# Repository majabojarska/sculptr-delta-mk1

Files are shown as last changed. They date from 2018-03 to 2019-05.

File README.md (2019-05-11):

# Sculptr Delta MK1

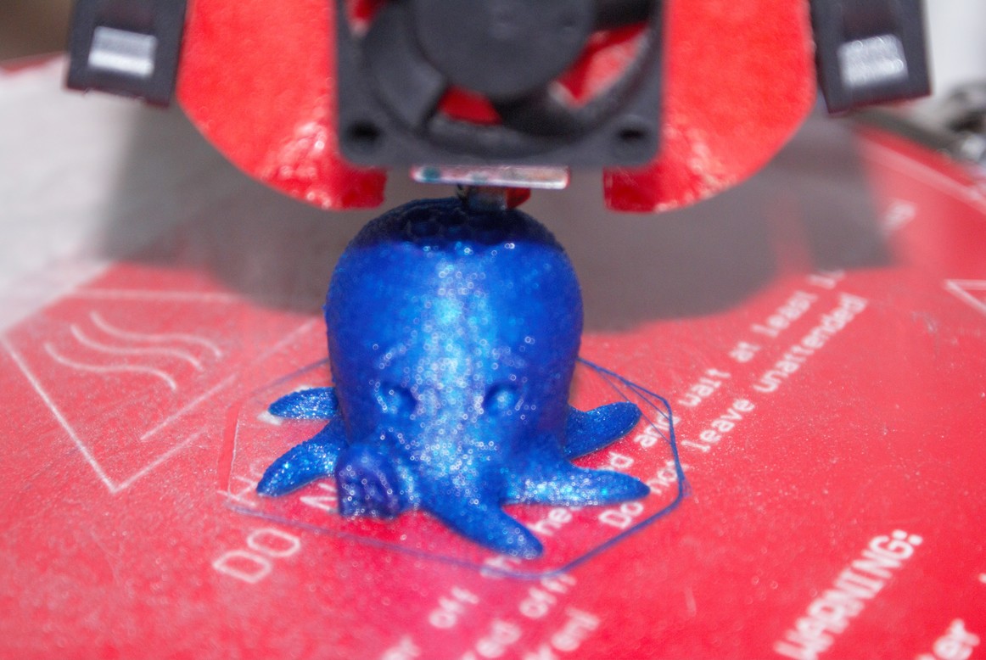
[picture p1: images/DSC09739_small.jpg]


## About

This is a modified version of the generic Marlin-1.1.x firmware pulled from the original github repository.
It's been set up to work with my build of Sculptr Delta MK1.
Might need a bit of tweaking to fully work with yours :) .

## Hardware description
- RAMPS 1.4 EFB
- RepRapDiscount FULL GRAPHIC Smart Controller
- 4xA4988 Stepper Drivers
- Normally closed (NC) endstops
- ATX PSU wired to power the hotend and heatbed from two separate channels
- E3Dv6 12V hotend
- MK2Y 220mm 12V circular heatbed with 4mm glass on top
- 100kOhm thermocouples
- Replaced heatbed MOSFET to IRLB3034 - more efficient, can handle higher loads easily with a small heatsink, generates much less heat
- OctoPrint hosted on Raspberry Pi 3 with a video stream
- 2x NeoPixel LEDs for print lighting

## Images
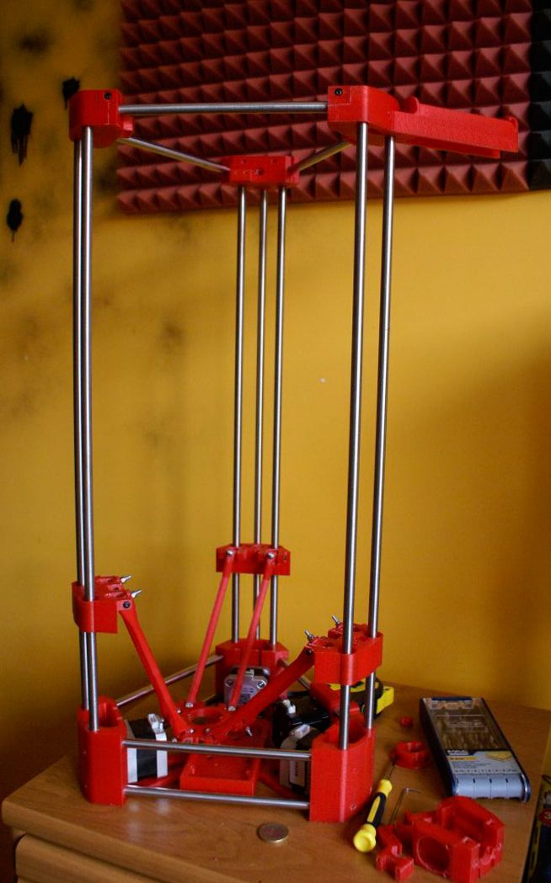
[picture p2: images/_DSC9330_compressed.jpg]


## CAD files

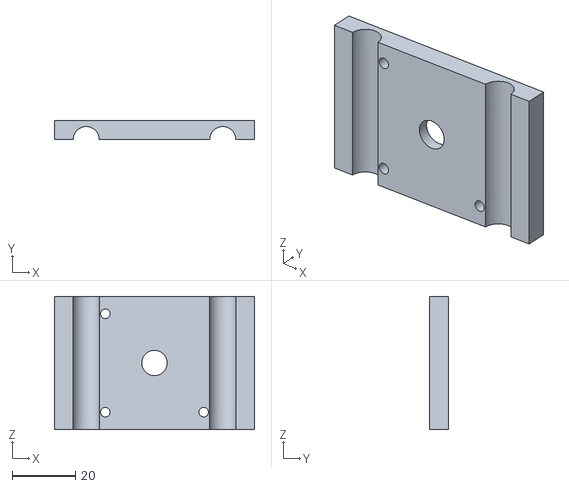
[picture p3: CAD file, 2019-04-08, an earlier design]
Thingiverse/files/extruder_support2.stl
63.0 x 6.00 x 42.0

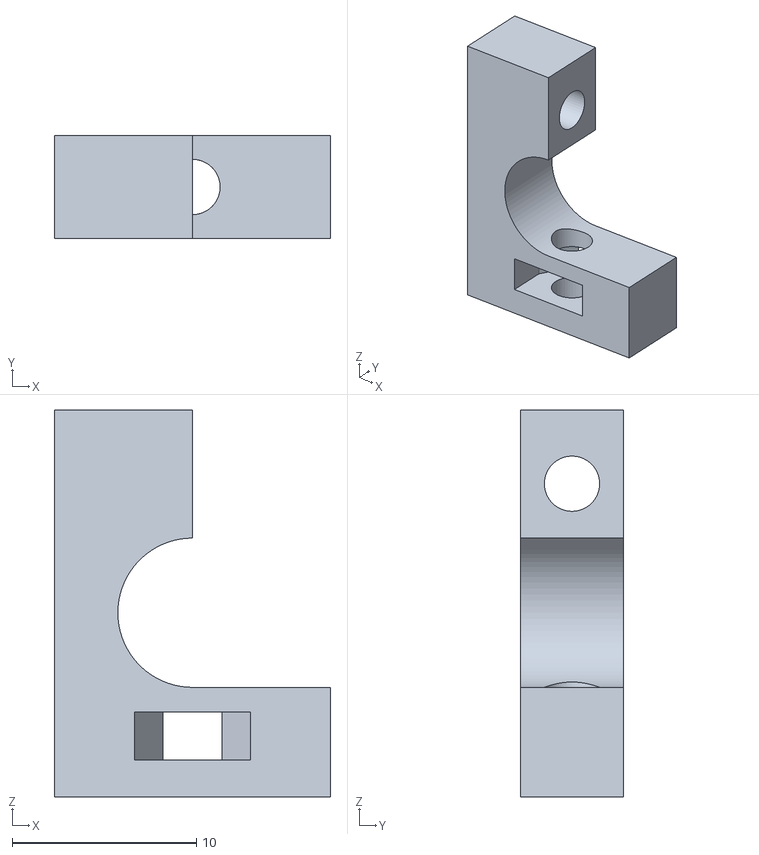
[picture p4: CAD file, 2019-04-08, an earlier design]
Thingiverse/files/bed_support_part1.stl
15.0 x 5.60 x 21.0

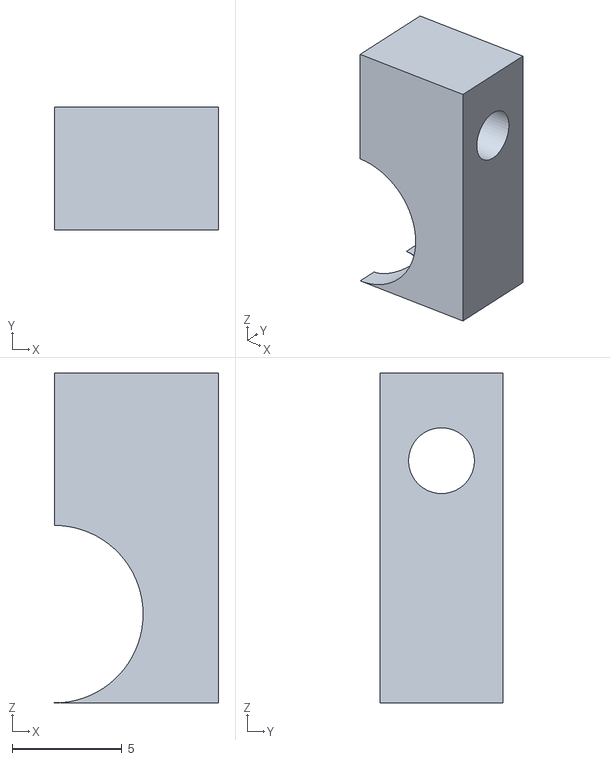
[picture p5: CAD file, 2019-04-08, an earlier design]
Thingiverse/files/bed_support_part2.stl
7.50 x 5.60 x 15.1

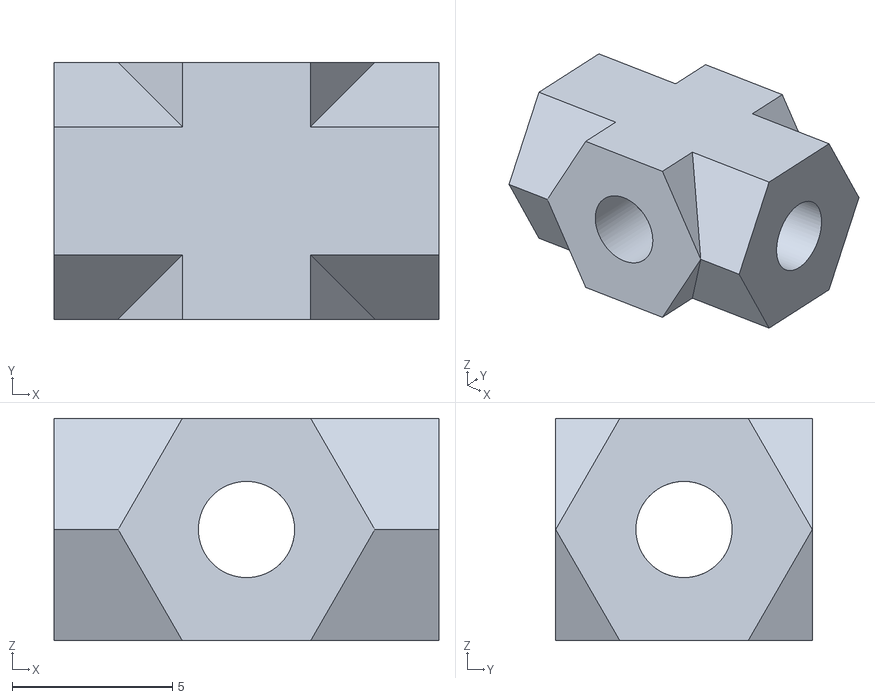
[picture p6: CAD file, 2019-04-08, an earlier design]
Thingiverse/files/joint.stl
12.0 x 8.00 x 6.93

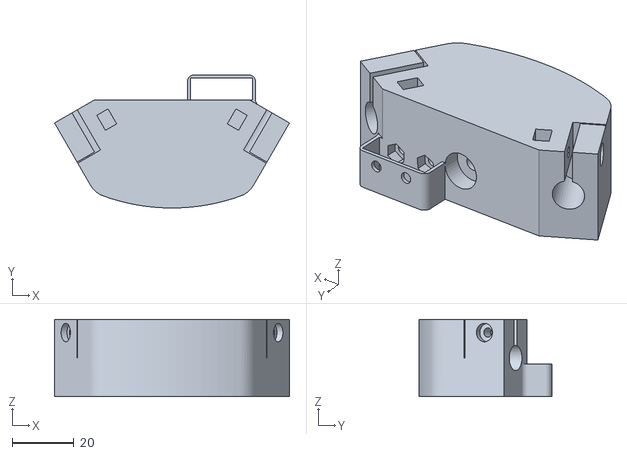
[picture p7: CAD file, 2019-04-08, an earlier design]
Thingiverse/files/top_frame.stl
76.0 x 43.0 x 25.0

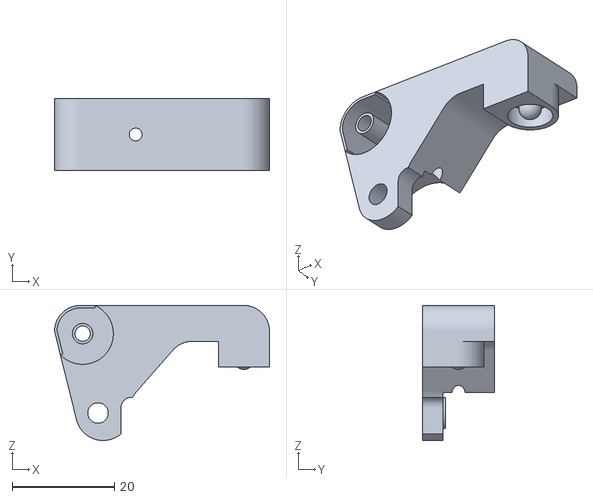
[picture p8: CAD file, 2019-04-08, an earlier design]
Thingiverse/files/extruder_arm.stl
42.0 x 14.0 x 26.4

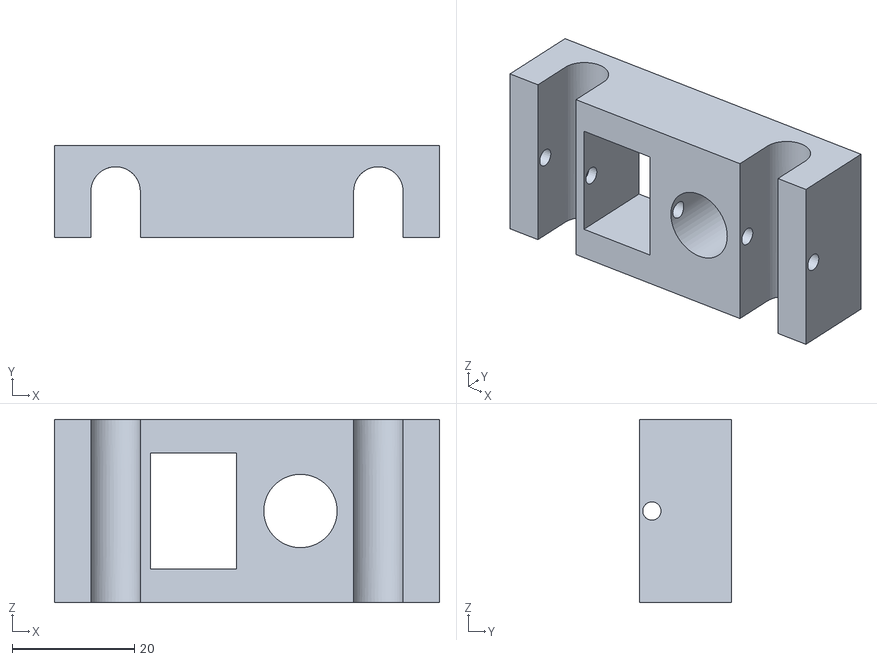
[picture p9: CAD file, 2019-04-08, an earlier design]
Thingiverse/files/switch_panel.stl
63.0 x 15.0 x 30.0

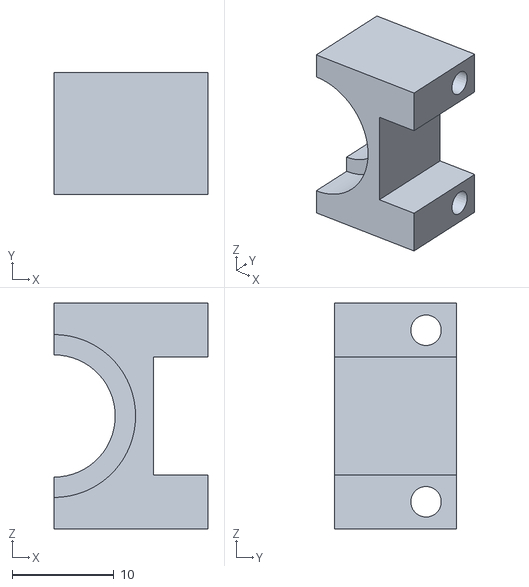
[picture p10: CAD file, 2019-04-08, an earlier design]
Thingiverse/files/e3d_blocker.stl
15.1 x 12.0 x 22.2

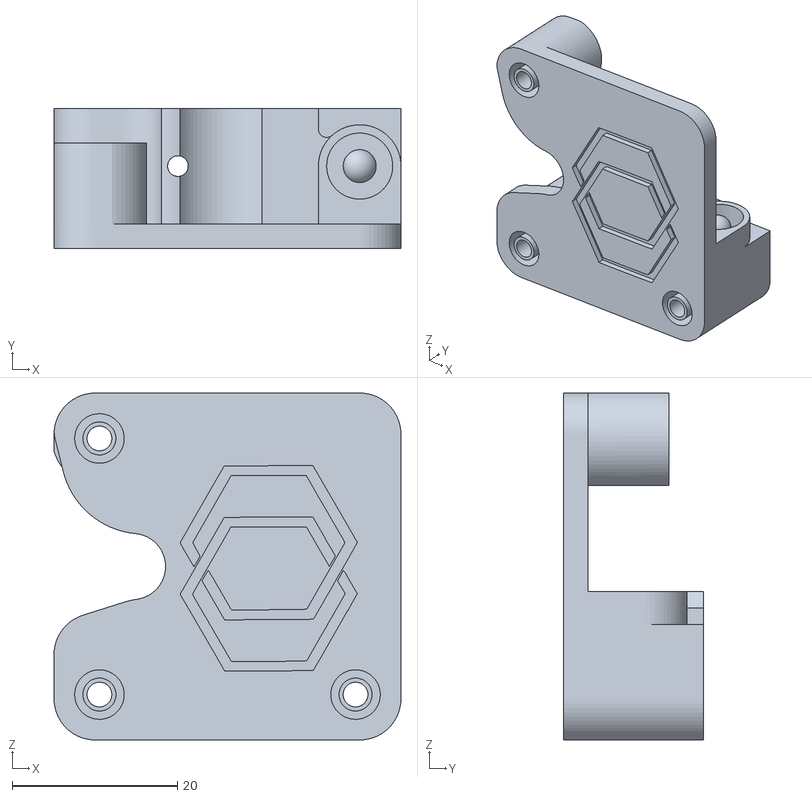
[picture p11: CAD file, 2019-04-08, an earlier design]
Thingiverse/files/extruder_body.stl
42.0 x 17.0 x 42.0

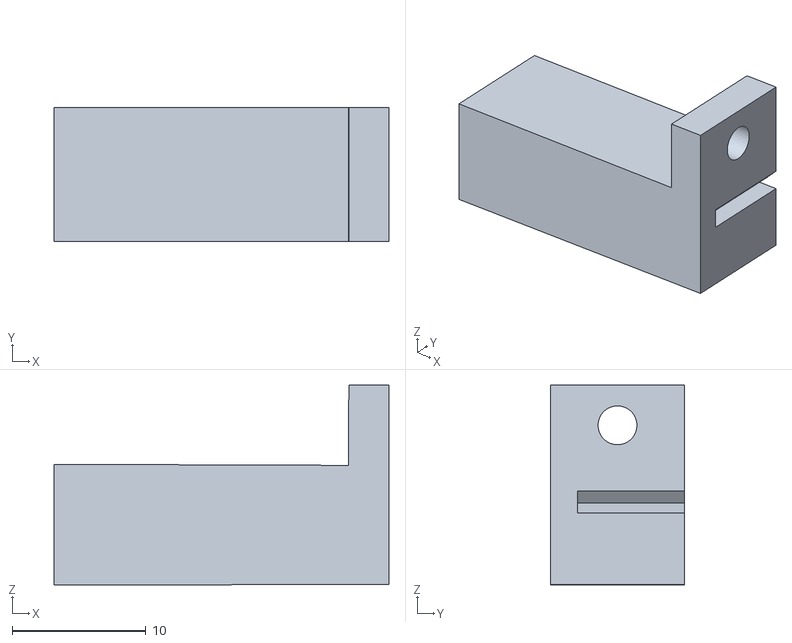
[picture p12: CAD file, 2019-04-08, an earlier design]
Thingiverse/files/GT2_belt_carriage.stl
25.0 x 10.0 x 14.9

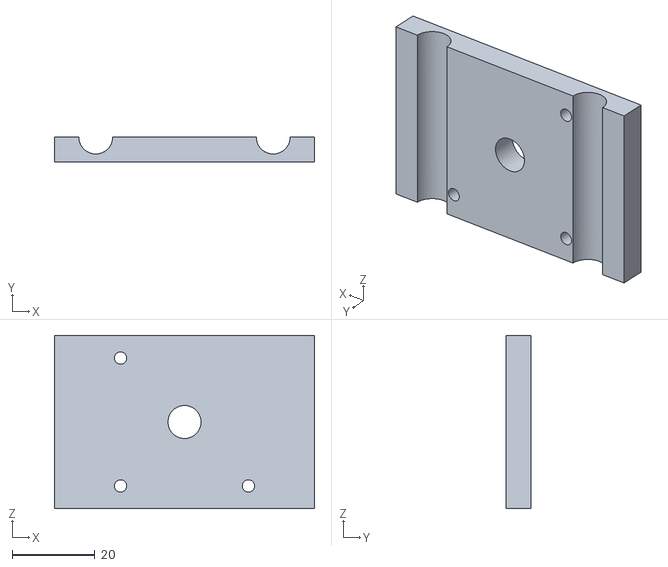
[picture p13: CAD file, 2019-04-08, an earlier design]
Thingiverse/files/extruder_support1.stl
63.0 x 6.00 x 42.0

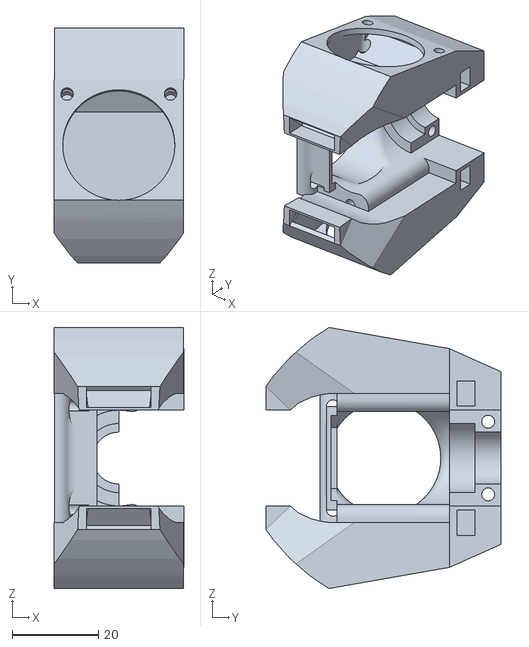
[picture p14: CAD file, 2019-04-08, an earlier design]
Thingiverse/files/hotend_fans.stl
30.1 x 54.5 x 60.5

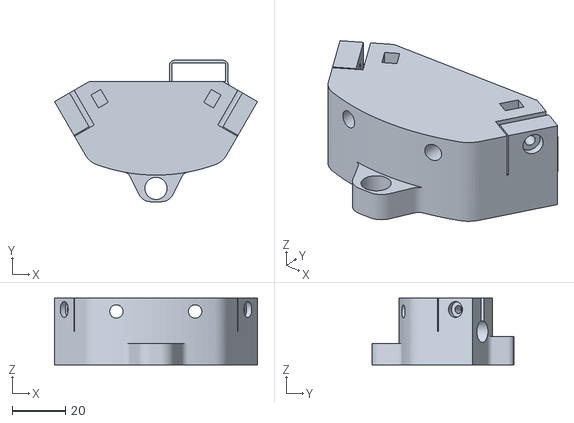
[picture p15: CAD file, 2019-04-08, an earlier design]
Thingiverse/files/top_frame_Z_axis.stl
76.0 x 53.0 x 25.0

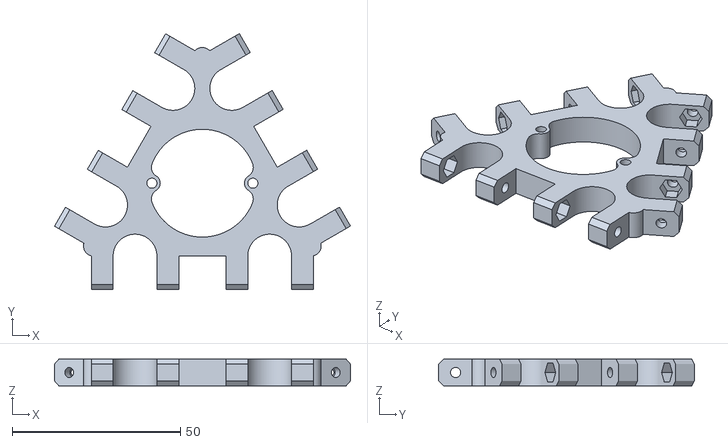
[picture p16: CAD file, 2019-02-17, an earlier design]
Thingiverse/files/platform.stl
87.9 x 76.0 x 8.00

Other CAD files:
Thingiverse/files/LCD_front_with_reset.stl
Thingiverse/files/LCD_front.stl
Thingiverse/files/foot.stl
Thingiverse/files/LCD_front_rods_support.stl
Thingiverse/files/150mm_rod.stl
Thingiverse/files/LCD_front_support.stl
Thingiverse/files/arduino_support.stl
Thingiverse/files/bed.dxf
Thingiverse/files/bottom_frame.stl
Thingiverse/files/bottom_frame_Z_axis.stl
Thingiverse/files/carriage.stl
Thingiverse/files/e3d_top.stl
Thingiverse/files/endstops_tube_fixing.stl
Thingiverse/files/top_frame_spool_holder.stl

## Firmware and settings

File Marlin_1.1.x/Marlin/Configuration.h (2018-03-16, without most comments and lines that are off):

#define CONFIGURATION_H
#define CONFIGURATION_H_VERSION 010107
#define STRING_CONFIG_H_AUTHOR "Maya" // Who made the changes.
#define SERIAL_PORT 0
#define BAUDRATE 115200
  #define MOTHERBOARD BOARD_RAMPS_14_EFB
#define CUSTOM_MACHINE_NAME "Sculptr Delta"
#define EXTRUDERS 1
#define DEFAULT_NOMINAL_FILAMENT_DIA 3.0
#define POWER_SUPPLY 1
#define TEMP_SENSOR_0 1
#define TEMP_SENSOR_1 0
#define TEMP_SENSOR_2 0
#define TEMP_SENSOR_3 0
#define TEMP_SENSOR_4 0
#define TEMP_SENSOR_BED 1
#define DUMMY_THERMISTOR_998_VALUE 25
#define DUMMY_THERMISTOR_999_VALUE 100
#define MAX_REDUNDANT_TEMP_SENSOR_DIFF 10
#define TEMP_RESIDENCY_TIME 10  // (seconds)
#define TEMP_HYSTERESIS 3       // (degC) range of +/- temperatures considered "close" to the target one
#define TEMP_WINDOW     1       // (degC) Window around target to start the residency timer x degC early.
#define TEMP_BED_RESIDENCY_TIME 0   // (seconds)
#define TEMP_BED_HYSTERESIS 3       // (degC) range of +/- temperatures considered "close" to the target one
#define TEMP_BED_WINDOW     1       // (degC) Window around target to start the residency timer x degC early.
#define HEATER_0_MINTEMP 10
#define HEATER_1_MINTEMP 10
#define HEATER_2_MINTEMP 10
#define HEATER_3_MINTEMP 10
#define HEATER_4_MINTEMP 10
#define BED_MINTEMP 10
#define HEATER_0_MAXTEMP 250
#define HEATER_1_MAXTEMP 220
#define HEATER_2_MAXTEMP 220
#define HEATER_3_MAXTEMP 220
#define HEATER_4_MAXTEMP 220
#define BED_MAXTEMP 100
#define PIDTEMP
#define BANG_MAX 255     // Limits current to nozzle while in bang-bang mode; 255=full current
#define PID_MAX BANG_MAX // Limits current to nozzle while PID is active (see PID_FUNCTIONAL_RANGE below); 255=full current
#define PID_K1 0.95      // Smoothing factor within the PID
  #define PID_FUNCTIONAL_RANGE 10 // If the temperature difference between the target temperature and the actual temperature
  #define  DEFAULT_Kp 33.01
  #define  DEFAULT_Ki 4.80
  #define  DEFAULT_Kd 56.79
#define PIDTEMPBED
#define MAX_BED_POWER 255 // limits duty cycle to bed; 255=full current
  #define  DEFAULT_bedKp 10.00
  #define  DEFAULT_bedKi .023
  #define  DEFAULT_bedKd 305.4
#define PREVENT_COLD_EXTRUSION
#define EXTRUDE_MINTEMP 170
#define PREVENT_LENGTHY_EXTRUDE
#define EXTRUDE_MAXLENGTH 200
#define THERMAL_PROTECTION_HOTENDS // Enable thermal protection for all extruders
#define THERMAL_PROTECTION_BED     // Enable thermal protection for the heated bed
#define DELTA
  #define DELTA_SEGMENTS_PER_SECOND 200
  #define DELTA_PRINTABLE_RADIUS 75.0 // mm
  #define DELTA_DIAGONAL_ROD 155.0 // mm
  #define DELTA_HEIGHT 226.50 // get this value from auto calibrate
  #define DELTA_ENDSTOP_ADJ { 0.0, 0.0, 0.0 } // get these from auto calibrate
  #define DELTA_RADIUS 77.20 //mm  Get this value from auto calibrate
  #define DELTA_TOWER_ANGLE_TRIM { 0.0, 0.0, 0.0 } // get these values from auto calibrate
#define USE_ZMIN_PLUG // a Z probe
#define USE_XMAX_PLUG
#define USE_YMAX_PLUG
#define USE_ZMAX_PLUG
#define ENDSTOPPULLUPS // Comment this out (using // at the start of the line) to disable the endstop pullup resistors
#define X_MIN_ENDSTOP_INVERTING false  // set to true to invert the logic of the endstop.
#define Y_MIN_ENDSTOP_INVERTING false  // set to true to invert the logic of the endstop.
#define Z_MIN_ENDSTOP_INVERTING true  // set to true to invert the logic of the endstop.
#define X_MAX_ENDSTOP_INVERTING false  // set to true to invert the logic of the endstop.
#define Y_MAX_ENDSTOP_INVERTING false  // set to true to invert the logic of the endstop.
#define Z_MAX_ENDSTOP_INVERTING false  // set to true to invert the logic of the endstop.
#define Z_MIN_PROBE_ENDSTOP_INVERTING true// set to true to invert the logic of the probe.
#define DEFAULT_AXIS_STEPS_PER_UNIT   { 80, 80, 80, 100 }  // default steps per unit for Kossel (GT2, 20 tooth)
#define DEFAULT_MAX_FEEDRATE          { 200, 200, 200, 25 }
#define DEFAULT_MAX_ACCELERATION      { 1000, 1000, 1000, 1000 }
#define DEFAULT_ACCELERATION          1000    // X, Y, Z and E acceleration for printing moves
#define DEFAULT_RETRACT_ACCELERATION  1000    // E acceleration for retracts
#define DEFAULT_TRAVEL_ACCELERATION   1000    // X, Y, Z acceleration for travel (non printing) moves
#define DEFAULT_XJERK                 15.0
#define DEFAULT_YJERK                 DEFAULT_XJERK
#define DEFAULT_ZJERK                 DEFAULT_XJERK // Must be same as XY for delta
#define DEFAULT_EJERK                 DEFAULT_XJERK
#define Z_MIN_PROBE_USES_Z_MIN_ENDSTOP_PIN
#define X_PROBE_OFFSET_FROM_EXTRUDER 47     // X offset: -left  +right  [of the nozzle]
#define Y_PROBE_OFFSET_FROM_EXTRUDER 13   // Y offset: -front +behind [the nozzle]
#define Z_PROBE_OFFSET_FROM_EXTRUDER -23.3  // Z offset: -below +above  [the nozzle]
#define XY_PROBE_SPEED 2000
#define Z_PROBE_SPEED_FAST HOMING_FEEDRATE_Z
#define Z_PROBE_SPEED_SLOW (Z_PROBE_SPEED_FAST / 8)
#define Z_CLEARANCE_DEPLOY_PROBE   15 // Z Clearance for Deploy/Stow
#define Z_CLEARANCE_BETWEEN_PROBES  2 // Z Clearance between probe points
#define Z_PROBE_OFFSET_RANGE_MIN -20
#define Z_PROBE_OFFSET_RANGE_MAX 20
#define X_ENABLE_ON 0
#define Y_ENABLE_ON 0
#define Z_ENABLE_ON 0
#define E_ENABLE_ON 0 // For all extruders
#define DISABLE_X false
#define DISABLE_Y false
#define DISABLE_Z false
#define DISABLE_E false // For all extruders
#define DISABLE_INACTIVE_EXTRUDER false // Keep only the active extruder enabled.
#define INVERT_X_DIR false // DELTA does not invert
#define INVERT_Y_DIR false
#define INVERT_Z_DIR false
#define INVERT_E0_DIR false
#define INVERT_E1_DIR false
#define INVERT_E2_DIR false
#define INVERT_E3_DIR false
#define INVERT_E4_DIR false
#define X_HOME_DIR 1  // deltas always home to max
#define Y_HOME_DIR 1
#define Z_HOME_DIR 1
#define X_BED_SIZE ((DELTA_PRINTABLE_RADIUS) * 2)
#define Y_BED_SIZE ((DELTA_PRINTABLE_RADIUS) * 2)
#define X_MIN_POS -(DELTA_PRINTABLE_RADIUS)
#define Y_MIN_POS -(DELTA_PRINTABLE_RADIUS)
#define Z_MIN_POS -2.0
#define X_MAX_POS DELTA_PRINTABLE_RADIUS
#define Y_MAX_POS DELTA_PRINTABLE_RADIUS
#define Z_MAX_POS MANUAL_Z_HOME_POS
#define MIN_SOFTWARE_ENDSTOPS
  #define MIN_SOFTWARE_ENDSTOP_X
  #define MIN_SOFTWARE_ENDSTOP_Y
  #define MIN_SOFTWARE_ENDSTOP_Z
#define MAX_SOFTWARE_ENDSTOPS
  #define MAX_SOFTWARE_ENDSTOP_X
  #define MAX_SOFTWARE_ENDSTOP_Y
  #define MAX_SOFTWARE_ENDSTOP_Z
#define AUTO_BED_LEVELING_UBL
#define DEBUG_LEVELING_FEATURE
  #define DELTA_PROBEABLE_RADIUS (DELTA_PRINTABLE_RADIUS - 10)
  #define SEGMENT_LEVELED_MOVES
  #define LEVELED_SEGMENT_LENGTH 5.0 // (mm) Length of all segments (except the last one)
  #define G26_MESH_VALIDATION   // Enable G26 mesh validation
    #define MESH_TEST_NOZZLE_SIZE     0.4   // (mm) Diameter of primary nozzle.
    #define MESH_TEST_LAYER_HEIGHT    0.2   // (mm) Default layer height for the G26 Mesh Validation Tool.
    #define MESH_TEST_HOTEND_TEMP   205.0   // (°C) Default nozzle temperature for the G26 Mesh Validation Tool.
    #define MESH_TEST_BED_TEMP       20.0   // (°C) Default bed temperature for the G26 Mesh Validation Tool.
  #define MESH_INSET 1              // Mesh inset margin on print area
  #define GRID_MAX_POINTS_X 10      // Don't use more than 15 points per axis, implementation limited.
  #define GRID_MAX_POINTS_Y GRID_MAX_POINTS_X
  #define _PX(R,A) (R) * cos(RADIANS(A))
  #define _PY(R,A) (R) * sin(RADIANS(A))
  #define UBL_PROBE_PT_1_X _PX(DELTA_PROBEABLE_RADIUS, 0)   // Probing points for 3-Point leveling of the mesh
  #define UBL_PROBE_PT_1_Y _PY(DELTA_PROBEABLE_RADIUS, 0)
  #define UBL_PROBE_PT_2_X _PX(DELTA_PROBEABLE_RADIUS, 30)
  #define UBL_PROBE_PT_2_Y _PY(DELTA_PROBEABLE_RADIUS, 30)
  #define UBL_PROBE_PT_3_X _PX(DELTA_PROBEABLE_RADIUS, -30)
  #define UBL_PROBE_PT_3_Y _PY(DELTA_PROBEABLE_RADIUS, -30)
  #define UBL_MESH_EDIT_MOVES_Z     // Sophisticated users prefer no movement of nozzle
  #define UBL_SAVE_ACTIVE_ON_M500   // Save the currently active mesh in the current slot on M500
#define Z_PROBE_END_SCRIPT "G1 X0 Y0 Z10 F6000"
#define BED_CENTER_AT_0_0
#define MANUAL_Z_HOME_POS DELTA_HEIGHT // Distance between the nozzle to printbed after homing
#define HOMING_FEEDRATE_Z  1000
#define EEPROM_SETTINGS // Enable for M500 and M501 commands
#define EEPROM_CHITCHAT   // Give feedback on EEPROM commands. Disable to save PROGMEM.
#define HOST_KEEPALIVE_FEATURE        // Disable this if your host doesn't like keepalive messages
#define DEFAULT_KEEPALIVE_INTERVAL 2  // Number of seconds between "busy" messages. Set with M113.
#define BUSY_WHILE_HEATING            // Some hosts require "busy" messages even during heating
#define PREHEAT_1_TEMP_HOTEND 205
#define PREHEAT_1_TEMP_BED     20
#define PREHEAT_1_FAN_SPEED   255 // Value from 0 to 255
#define PREHEAT_2_TEMP_HOTEND 240
#define PREHEAT_2_TEMP_BED    100
#define PREHEAT_2_FAN_SPEED   255 // Value from 0 to 255
#define PRINTJOB_TIMER_AUTOSTART
#define LCD_LANGUAGE en
#define DISPLAY_CHARSET_HD44780 JAPANESE
#define SDSUPPORT
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

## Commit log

2018-03-16 New UBL bed mesh
2018-03-16 Disabled DISABLE_INACTIVE_EXTRUDER
    [Configuration.h]
2019-02-17 add image to readme
    [150mm_rod.stl, Configuration.h, Configuration_adv.h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]
2019-02-17 repo cleanup
    [150mm_rod.stl, Configuration.h, Configuration_adv.h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]
2019-04-08 New repo
    [150mm_rod.stl, Configuration.h, Configuration_adv.h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]

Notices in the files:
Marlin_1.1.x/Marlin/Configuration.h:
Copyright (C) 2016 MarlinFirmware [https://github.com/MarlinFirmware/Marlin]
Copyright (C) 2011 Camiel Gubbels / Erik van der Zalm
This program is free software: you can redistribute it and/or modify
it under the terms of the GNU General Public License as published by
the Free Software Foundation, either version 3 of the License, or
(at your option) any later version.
